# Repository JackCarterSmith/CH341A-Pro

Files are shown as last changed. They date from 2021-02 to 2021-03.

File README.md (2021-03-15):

# CH341A-Pro2

Originally by Upcycle-Electronics, thanks to him! (https://github.com/Upcycle-Electronics/CH341A-Pro)

I've added a voltage selection jumper, swap the memory orientation (to follow the last software revision) and removed the "useless" serial I/O.
For now, this version haven't been tested... Please be advice!

Schematic:
https://github.com/JackCarterSmith/CH341A-Pro/blob/master/ch341Apro_schematicV02a.pdf

V1

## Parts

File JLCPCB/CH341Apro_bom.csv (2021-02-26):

Comment | Designator | Footprint | LCSC
12M | Y1 | Crystal:Crystal_SMD_5032-2Pin_5.0x3.2mm | C112573
 | J4 | Connector_PinHeader_2.54mm:PinHeader_1x09_P2.54mm_Vertical
PWR | D1 | LED_SMD:LED_0603_1608Metric | C72044
ZIF-16 | J3 | Socket:DIP_Socket-16_W4.3_W5.08_W7.62_W10.16_W10.9_3M_216-3340-00-0602J
RUN | D2 | LED_SMD:LED_0603_1608Metric | C72043
USB_A | J1 | Connector_USB:USB_A_CNCTech_1001-011-01101_Horizontal
472 | C3 | Capacitor_SMD:C_0603_1608Metric | C8032
20p | C6,C5 | Capacitor_SMD:C_0402_1005Metric | C1554
104 | C2,C1 | Capacitor_SMD:C_0603_1608Metric | C19702
V_SEL | J5 | Connector_PinHeader_2.54mm:PinHeader_1x03_P2.54mm_Vertical
CH341a | U2 | Package_SO:SOIC-28W_7.5x17.9mm_P1.27mm | C13517
AMS1117-3.3 | U1 | Package_TO_SOT_SMD:SOT-223-3_TabPin2 | C351784
 | JP1 | Jumper:SolderJumper-2_P1.3mm_Open_Pad1.0x1.5mm
222 | RN1 | Resistor_SMD:R_Array_Convex_4x0603 | C12001
0R | R1 | Resistor_SMD:R_0603_1608Metric | C207010

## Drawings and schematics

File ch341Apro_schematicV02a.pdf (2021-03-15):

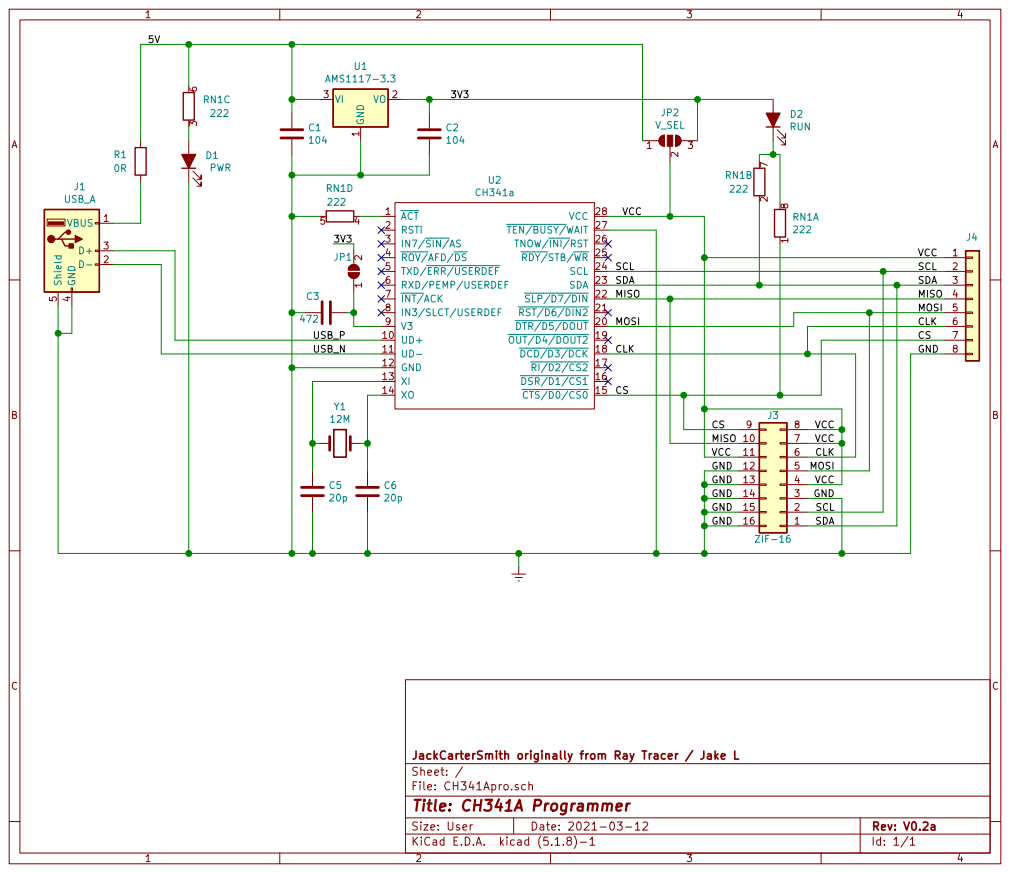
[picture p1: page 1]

SDA USB_P 4

CSMOSI MISO 5

10 | 7 VCC
11 | 6

13 | 4 VCC
14 | 3
15 | 2 SCL SDA
16 | 1

File: CH341Apro.sch Sheet: / JackCarterSmith originally from Ray Tracer / Jake L

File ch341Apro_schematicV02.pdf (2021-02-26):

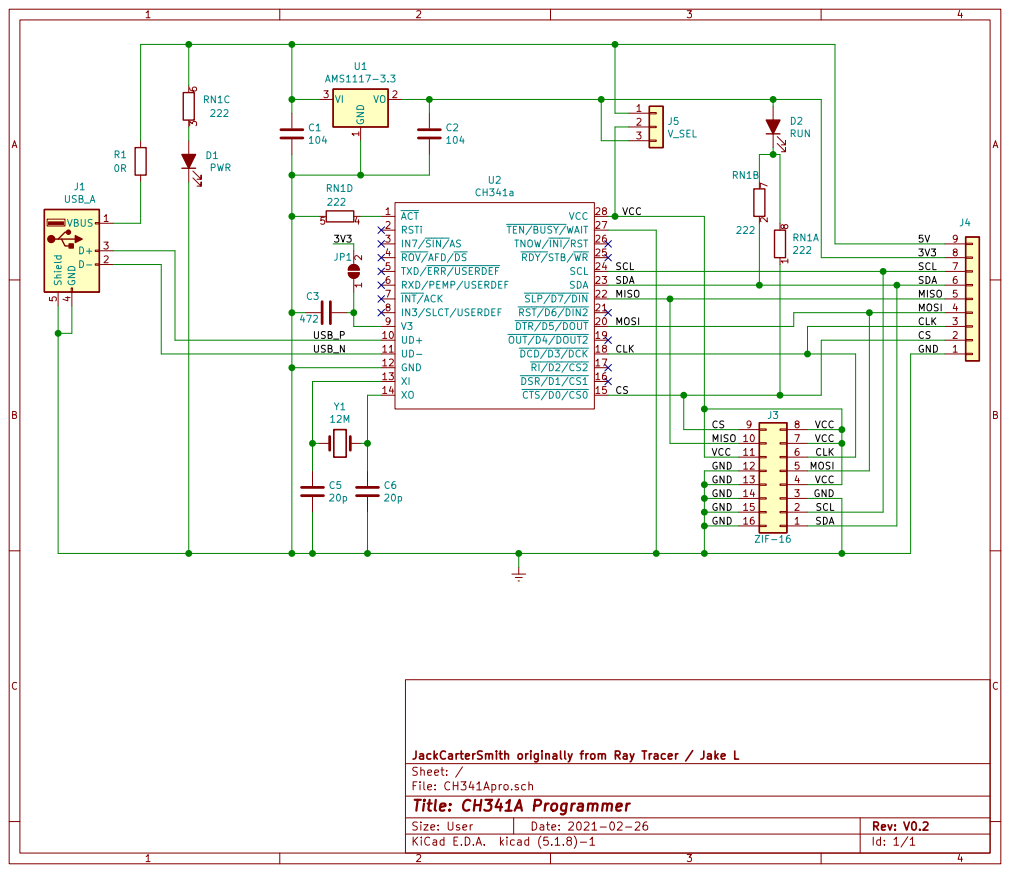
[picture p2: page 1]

10 | 7 VCC
11 | 6

13 | 4
GND 14 | 3
15 | 2
16 | 1 SDA

File: CH341Apro.sch Sheet: / JackCarterSmith originally from Ray Tracer / Jake L

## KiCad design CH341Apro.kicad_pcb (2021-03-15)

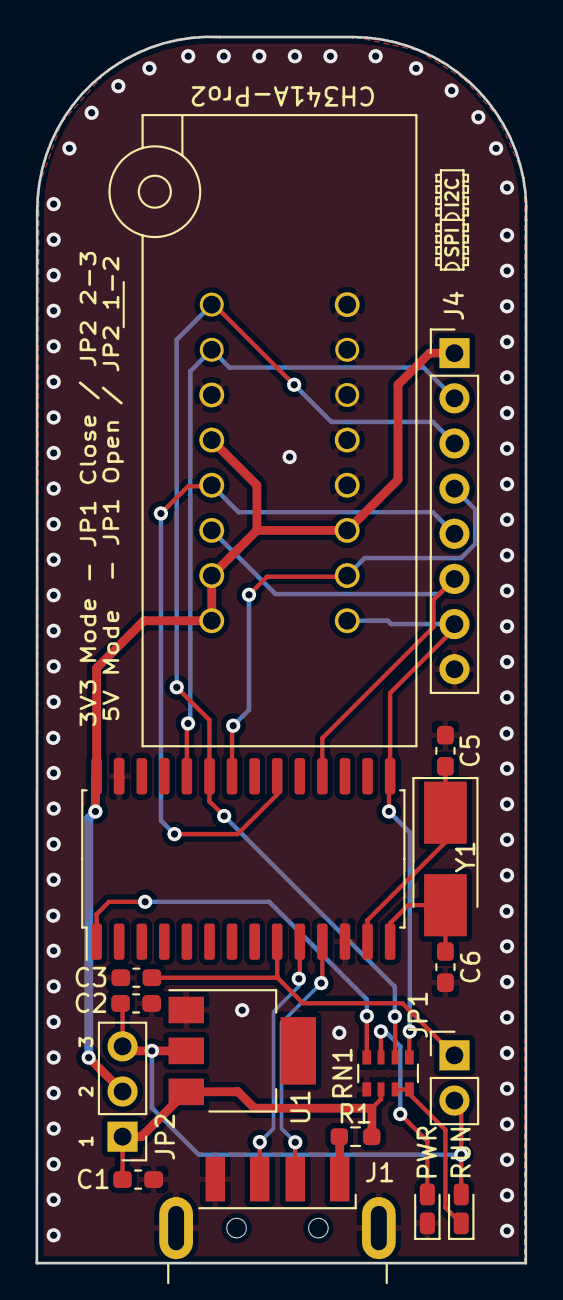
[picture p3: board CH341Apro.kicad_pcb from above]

Board: 2 copper layers, 27.5 x 69.0 mm, 17 parts (0 on the bottom side), 19 nets.

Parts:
C1, C2: 104; C_0603_1608Metric_Pad1.05x0.95mm_HandSolder
C3: 472; C_0603_1608Metric_Pad1.05x0.95mm_HandSolder
C5, C6: 20p; C_0603_1608Metric_Pad1.05x0.95mm_HandSolder
J1: USB_A; USB_A_CNCTech_1001-011-01101_Horizontal
J3: ZIF-16; DIP_Socket-16_W4.3_W5.08_W7.62_W10.16_W10.9_3M_216-3340-00-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
J4: PinHeader_1x08_P2.54mm_Vertical
JP1: PinHeader_1x02_P2.54mm_Vertical
JP2: V_SEL; PinHeader_1x03_P2.54mm_Vertical
PWR: PWR; LED_0603_1608Metric_Castellated
R1: 0R; R_0603_1608Metric_Pad0.98x0.95mm_HandSolder
RN1: 222; R_Array_Convex_4x0603
RUN: RUN; LED_0603_1608Metric_Castellated
U1: AMS1117-3.3; SOT-223-3_TabPin2
U2: CH341a; SOIC-28W_7.5x17.9mm_P1.27mm
Y1: 12M; Crystal_SMD_5032-2Pin_5.0x3.2mm_HandSoldering

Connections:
/3V3: C2.1, JP1.2, JP2.3, RUN.2, U1.2
/5V: C1.1, JP2.1, R1.1, RN1.6, U1.3
/CLK: J3.6, J4.6, U2.18
/CS: J3.9, J4.7, RN1.1, U2.15
/MISO: J3.10, J4.4, U2.22
/MOSI: J3.5, J4.5, U2.20
/SCL: J3.2, J4.2, U2.24
/SDA: J3.1, J4.3, RN1.2, U2.23
/USB_N: J1.2, U2.11
/USB_P: J1.3, U2.10
/VCC: J3.4, J3.7, J3.8, J3.11, J4.1, JP2.2, U2.28
Earth: C1.2, C2.2, C3.1, C5.2, C6.2, J1.4, J1.5, J3.3, J3.12, J3.13, J3.14, J3.15, J3.16, J4.8, PWR.1, RN1.5, U1.1, U2.12, U2.27
unnamed: C3.2, JP1.1, U2.9
unnamed: C5.1, U2.13, Y1.1
unnamed: C6.1, U2.14, Y1.2
unnamed: PWR.2, RN1.3
unnamed: RN1.7, RN1.8, RUN.1
unnamed: J1.1, R1.2
unnamed: RN1.4, U2.1

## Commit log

2021-02-26 Updated schematic and PCB
    Read the README file for details
    [CH341Apro.sch]
2021-02-26 Add JLCPCB assembly infos
    [CH341Apro-B_Cu.gbr, CH341Apro-B_Mask.gbr, CH341Apro-B_SilkS.gbr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]
2021-03-12 Major ergo change
    Updated components footprints for hand soldering.
    Change VCC routing.
    Add JP1/2 for selecting operating voltage.
    [CH341Apro-B_Cu.gbr, CH341Apro-B_Mask.gbr, CH341Apro-B_SilkS.gbr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]
2021-03-15 Changed drawing and placement
    [CH341Apro-B_Cu.gbr, CH341Apro-B_Mask.gbr, CH341Apro-B_SilkS.gbr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]
